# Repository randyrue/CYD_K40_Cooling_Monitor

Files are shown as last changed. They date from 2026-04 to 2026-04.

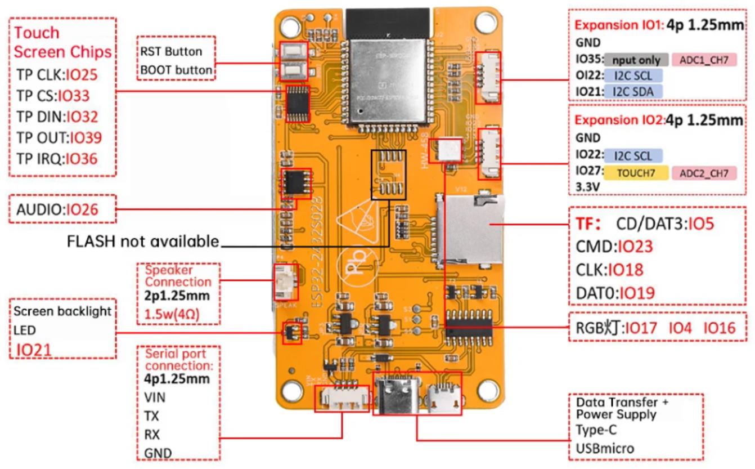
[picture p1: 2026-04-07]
pics/pinout.png

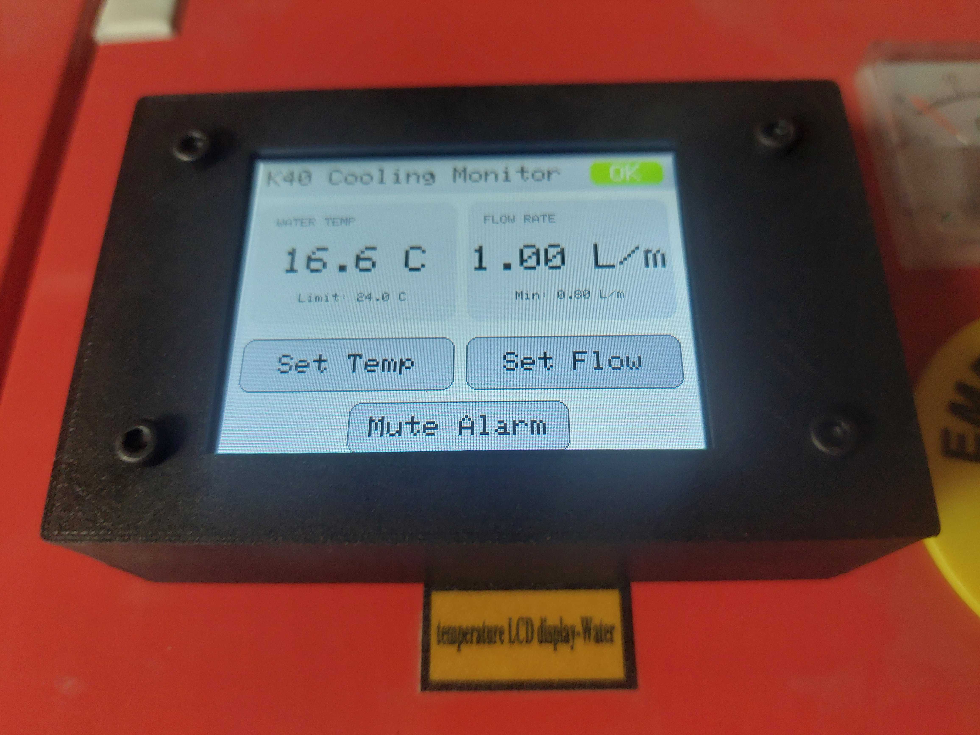
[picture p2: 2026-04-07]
pics/CYD_K40.jpg

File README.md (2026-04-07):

ESP32 Cheap Yellow Device K40 Laser Cooling Monitor

The CYD is about a perfect solution for upgrading the monitoring of cooling for a K40 CO2 laser cutter. Water flow and temperature are measured and if they go out of bounds (too warm or flow too low) the laser output is disabled.

My defaults are temp <= 24C and flow >= 0.8L/m. Change them in the code if your needs vary.

Minimal components are needed:

CYD
https://www.amazon.com/dp/B0CLR7MQ91
This is the one I used. There are many slight variations. You might need to fiddle with your User_Setup.h if yours is different. For example, I had to dink around for a while to get some colors to make sense.

DS18B20 temperature probe
https://www.amazon.com/dp/B012C597T0
Needs a 4K7 pull-up resistor between +V and the data line. Specs call for connecting the resistor to 3.3V, which you could get from the CN1 connector if needed, but mine works fine connected to 5V. For mine I added it in the middle of the cable to the temp sensor as long as I was splicing wires and wrapping the splices in heat shrink. This simplifies what would otherwise be your only needed wiring across the ports of the CYD.

GR-R401 fluid flow counter
https://www.amazon.com/dp/B07RF57QF8

Relay Module
https://www.amazon.com/dp/B00LW15A4W

Connectors for the onboard jacks: you'll need a few more than the one supplied with the CYD
https://www.amazon.com/dp/B0G146WVC1

Small Speaker

Case (STL file and SCAD are included here)
https://www.thingiverse.com/thing:7330724
Case design is a remix with no holes for connectors and extra space around the edges for JST headers. I drilled holes through the front for the CYD mounting holes, and a large hole through the back for wires to pass through. I should have also included one hole for the USB C jack in case I want to reflash the thing without needing to remove it. I've included the STL and also the hacked SCAD file, mod it to your preference.

A few other things make installation and maintenance easier, like:

Connector pigtails for the sensors - Tip - Reverse the M/F pigtail connectors for the temp and flow sensor connections to avoid confusion when climbing under your bench to connect them. That is, put the M on the controller side and the F on the sensor side for one, and the F on the controller side and the M on the sensor side for the other.
https://www.amazon.com/dp/B071H5XCN5

3-Conductor Wire - I added about four feet of three conductor wire between the sensors and the connector pigtails, with tidy splices and heat shrink tubing and for the temp sensor, its pullup resistor in one of the junctions (see Temperature Probe note above).
https://www.amazon.com/dp/B08JTZKN4M

Heat Shrink Tubing

Double Sided Tape

Hookup Wire

Connections to the K40: You essentially need to tap into +5VDC, ground, and wire the relay module's "NO" (normally open) side into the wire to the "P" connection on your high voltage power supply. Easy Peasy.

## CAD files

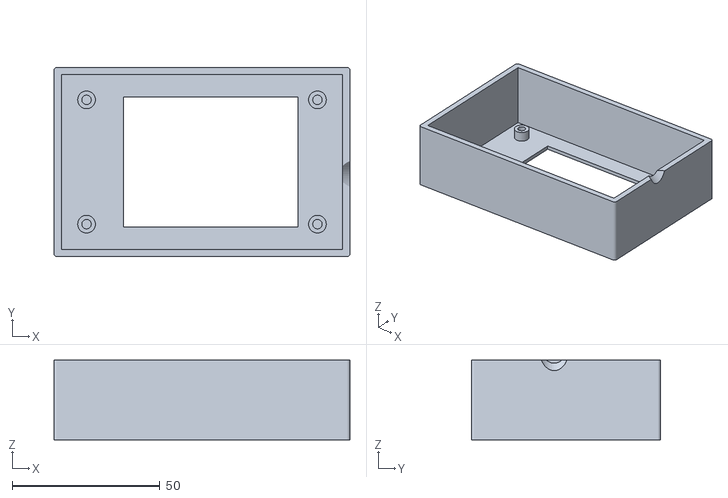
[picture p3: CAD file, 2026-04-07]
case/CYD_box.stl
100.0 x 64.0 x 27.0

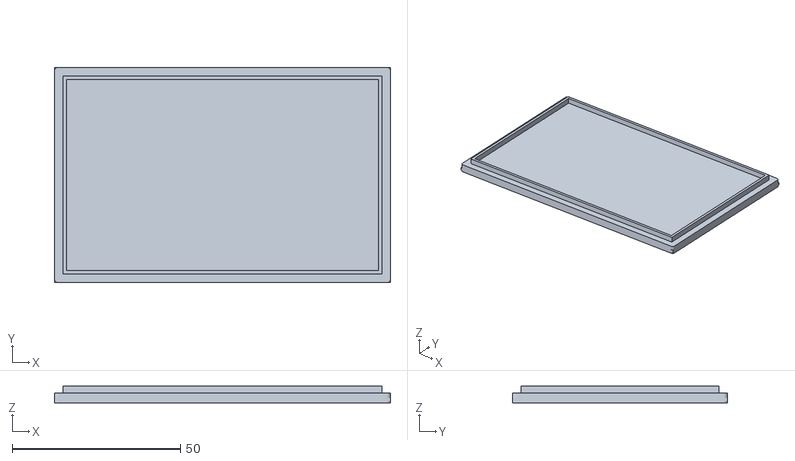
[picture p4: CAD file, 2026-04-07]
case/CYD_lid.stl
100.0 x 64.0 x 5.00

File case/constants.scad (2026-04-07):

// Constants
board_y_width = 51;
board_x_length = 87;
wall_thickness = 1.5;

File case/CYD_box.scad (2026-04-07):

// v4
$fn=40;


include <constants.scad>    // things shared with the lid
box_height = 26;
display_width = 44;
display_length = 59;
display_x_offset = 3;  // from the antenna end
display_y_offset = 4;
display_thickness = 3;  // from the main board
overlap = 0.01;
screw_mount_inset = 6;
screw_mount_height = 4;
screw_mount_radius = 3;
screw_hole_radius = 1.6;
board_thickness = 1.5;
usb_width = 12;
usb_y_offset = (screw_mount_height / 2) - 1.5;
opening_depth = 4;  // opening hole depth
board_top_z = screw_mount_height + board_thickness + wall_thickness; // opening hole z

include <roundedcube.scad>
//translate([-1,-1,0]) cube([100,64,10]);

difference() {
    minkowski() {
        cube([board_x_length+(wall_thickness*2+8), board_y_width+(wall_thickness*2+8), box_height]);
        cylinder(r=1,h=1);
        }
    
    // box main cavity
    translate([wall_thickness, wall_thickness, wall_thickness])
    cube([board_x_length+8, board_y_width+8, box_height]);
    
    // diplay opening
    translate([4+ (board_x_length / 2), 4+board_y_width / 2, -overlap])
    translate([wall_thickness+display_x_offset, wall_thickness, 0])
    cube([display_length, display_width, box_height], center=true);
    
    // USB-C port
    translate([-overlap, (board_y_width / 2) + wall_thickness, (box_height / 2) + usb_y_offset])
    roundedcube([10, usb_width, 6], radius = 2, center=true);
    
    // fingernail slot on end to help take off the lid
    finger_hole_radius=5;
    translate([board_x_length+finger_hole_radius+8, (board_y_width / 2) + wall_thickness, box_height+3.5])
    rotate([0,-45,0])
    cylinder(h=10, r=finger_hole_radius, center=true);

    // UART opening
    uart_width = 10;
    uart_height = 5;
    uart_start_x = 30.5 + wall_thickness;  // left edge
    //translate([uart_start_x, -overlap, board_top_z])
    //cube([uart_width, uart_height, opening_depth]);
    
    // SD Card opening
    sd_width = 16;
    sd_height = 2;
    sd_start_x = 43 + wall_thickness;
    //translate([sd_start_x, -overlap, board_top_z])
    //cube([sd_width, opening_depth, sd_height]);
    
    // SPI socket opening
    spi_width = 8;
    spi_height = 5;
    spi_start_x = 47.5 + wall_thickness;
    translate([spi_start_x, board_y_width + overlap, board_top_z])
    cube([spi_width, spi_height, opening_depth]);
    
    // IO35 socket opening
    io35_width = 8;
    io35_height = 5;
    io35_start_x = 64 + wall_thickness;
    translate([io35_start_x, board_y_width + overlap, board_top_z])
    cube([io35_width, io35_height, opening_depth]);
}

// screw mounts
corner_screws();

module corner_screws() {
    // right edge near USB socket
    translate([4+screw_mount_inset, 
        screw_mount_inset+4, 
        wall_thickness])
    screw_mount();
    
    // left edge near USB socket
    translate([4+screw_mount_inset, 
        board_y_width - screw_mount_inset + (wall_thickness*2)+4, 
        wall_thickness])
    screw_mount();
    
    // left far end from USB
    translate([4+board_x_length - screw_mount_inset + (wall_thickness*2), 
        board_y_width - screw_mount_inset + (wall_thickness*2)+4, 
        wall_thickness])
    screw_mount();
    
    // right far end from USB
    translate([4+board_x_length - screw_mount_inset + (wall_thickness*2), 
        screw_mount_inset+4, 
        wall_thickness])
    screw_mount();
}

module screw_mount() {
    //translate([6, 6, wall_thickness - overlap])
    difference() {
        cylinder(screw_mount_height, screw_mount_radius, screw_mount_radius); // h, r1, r2
        
        translate([0,0,wall_thickness])
        cylinder(screw_mount_height, screw_hole_radius, screw_hole_radius); // h, r1, r2
    }

}

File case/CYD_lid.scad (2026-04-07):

// Lid for the box
$fn=20;

include <constants.scad>
lid_layer_thickness = 2;
lid_inset = 0.2;

// top part full width
minkowski() {
    cube([8+board_x_length+(wall_thickness*2), 8+board_y_width+(wall_thickness*2), lid_layer_thickness], center = true);
    cylinder(r=1,h=1);
    }
translate([0, 0, lid_layer_thickness])
difference() {
// bit that fits into the hole in the box
    cube([8+board_x_length - lid_inset, 8+board_y_width - lid_inset, lid_layer_thickness+2], center = true);
    translate([0, 0, 0.1])
    cube([8+board_x_length - lid_inset - lid_layer_thickness, 8+board_y_width - lid_inset - lid_layer_thickness, lid_layer_thickness+2], center = true);

}

cube([100,64,1],center=true);

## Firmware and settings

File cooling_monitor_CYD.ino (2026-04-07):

// =============================================================================
//  K40 Laser Cooling Monitor — ESP32 Cheap Yellow Display (ESP32-2432S028)
// =============================================================================
//
//  Hardware connections:
//    DS18B20 data        -> GPIO 22  (P3 connector), 4.7kOhm pullup to 3.3V
//    DS18B20 VCC         -> 5V
//    DS18B20 GND         -> GND
//    Flow sensor signal  -> GPIO 35  (P3 connector)
//    Flow sensor VCC     -> 5V
//    Flow sensor GND     -> GND
//    Laser relay signal  -> GPIO 27  (CN1 connector)
//    Speaker (onboard)   -> GPIO 26  (SPEAK connector)
//    Power/GND           -> Serial port next to the USB C port (P1 connector)  
//
//  Relay wiring:
//    GPIO 27 is 3.3V logic. Use a relay module with 3.3V trigger, or drive
//    a 5V relay coil via a small NPN transistor (e.g. 2N2222). Relay output goes
//    connects between the existing connection to the "P" pin on the high voltage
//    power supply.
//
//  DS18B20 pullup:
//    4.7kOhm resistor between GPIO 22 and 5V. Note that specs call to connect it
//    to 3.3V but 5V seems to work and simplifies wiring.
//
//  Libraries required (Arduino Library Manager):
//    TFT_eSPI by Bodmer
//    XPT2046_Touchscreen by Paul Stoffregen
//    OneWire by Paul Stoffregen
//    DallasTemperature by Miles Burton
//
//  See User_Setup.h block at the bottom of this file. 
//
//  Boots in live mode. Hold the bottom button 3 seconds to toggle test mode.
//  Set minFlow to 0.00 L/m to disable flow fault checking entirely.
// =============================================================================

#include <TFT_eSPI.h>
#include <XPT2046_Touchscreen.h>
#include <OneWire.h>
#include <DallasTemperature.h>

// ---------------------------------------------------------------------------
//  Pin definitions
// ---------------------------------------------------------------------------
#define FLOW_SENSOR_PIN     35
#define DS18B20_PIN         22
#define RELAY_PIN           27
#define SPEAKER_PIN         26
#define TOUCH_CS            33
#define TOUCH_IRQ           36

// ---------------------------------------------------------------------------
//  DS18B20
// ---------------------------------------------------------------------------
OneWire oneWire(DS18B20_PIN);
DallasTemperature sensors(&oneWire);

// ---------------------------------------------------------------------------
//  Flow sensor
// ---------------------------------------------------------------------------
#define FLOW_CALIBRATION    98.0f      // pulses per litre/minute

// ---------------------------------------------------------------------------
//  Defaults
// ---------------------------------------------------------------------------
#define DEFAULT_MAX_TEMP    24.0f      // C   — above this triggers alarm
#define DEFAULT_MIN_FLOW     0.8f      // L/min — below this triggers alarm (0 = disabled)

// ---------------------------------------------------------------------------
//  Display / touch objects
// ---------------------------------------------------------------------------
TFT_eSPI tft = TFT_eSPI();
SPIClass touchSPI(VSPI);
XPT2046_Touchscreen touch(TOUCH_CS, TOUCH_IRQ);

// Touch calibration — confirmed from all four corner taps:
//   top-left:    raw( 467,  747)   top-right:    raw(3799,  677)
//   bottom-left: raw( 450, 3520)   bottom-right: raw(3769, 3670)
#define TS_MINX   450
#define TS_MAXX  3799
#define TS_MINY   677
#define TS_MAXY  3670

// ---------------------------------------------------------------------------
//  Globals
// ---------------------------------------------------------------------------
volatile uint32_t pulseCount = 0;
float flowRate  = 0.0f;
float waterTemp = 99.0f;   // safe default — triggers alarm until real reading

float maxTemp = DEFAULT_MAX_TEMP;
float minFlow = DEFAULT_MIN_FLOW;

bool alarmActive  = false;
bool alarmSilent  = false;
bool testMode     = false;   // boots in live mode; hold bottom button 3s to toggle

unsigned long lastFlowCalc   = 0;
unsigned long lastAlarmTone  = 0;
unsigned long muteHoldStart  = 0;
bool          muteHolding    = false;
uint8_t       muteReleaseCnt = 0;   // consecutive no-touch reads to confirm lift-off
#define RELEASE_NEEDED  6           // ~6 x 10ms = 60ms silence = genuine release

enum Screen { SCREEN_MAIN, SCREEN_SET_TEMP, SCREEN_SET_FLOW };
Screen currentScreen = SCREEN_MAIN;

// ---------------------------------------------------------------------------
//  ISR — counts flow sensor pulses
// ---------------------------------------------------------------------------
void IRAM_ATTR flowPulse() { pulseCount++; }

// ---------------------------------------------------------------------------
//  Read DS18B20 — returns 99.0 if disconnected so alarm fires safely
// ---------------------------------------------------------------------------
float readTemperature() {
  sensors.requestTemperatures();
  float t = sensors.getTempCByIndex(0);
  if (t == DEVICE_DISCONNECTED_C) return 99.0f;
  return t;
}

// ---------------------------------------------------------------------------
//  Flow rate — call every second, uses elapsed time for accuracy
// ---------------------------------------------------------------------------
void updateFlowRate() {
  unsigned long now     = millis();
  unsigned long elapsed = now - lastFlowCalc;
  if (elapsed < 1000) return;
  noInterrupts();
  uint32_t pulses = pulseCount;
  pulseCount = 0;
  interrupts();
  flowRate     = ((1000.0f / elapsed) * pulses) / FLOW_CALIBRATION;
  lastFlowCalc = now;
}

// ---------------------------------------------------------------------------
//  Relay / speaker
// ---------------------------------------------------------------------------
void setLaser(bool enable)  { digitalWrite(RELAY_PIN, enable ? HIGH : LOW); }
void soundAlarm()           { tone(SPEAKER_PIN, 3000, 120); }
void silenceAlarm()         { noTone(SPEAKER_PIN); }

// ---------------------------------------------------------------------------
//  Colours
//  0xE007 is byte-swapped green for this ST7789 board variant
// ---------------------------------------------------------------------------
#define COLOR_BG      TFT_BLACK
#define COLOR_HEADER  0x1082
#define COLOR_OK      0xE007
#define COLOR_WARN    TFT_RED
#define COLOR_ACCENT  0xFD20
#define COLOR_TEXT    TFT_WHITE
#define COLOR_SUBTEXT 0xAD75
#define COLOR_BTN     0x2945

// ---------------------------------------------------------------------------
//  Draw rounded button
// ---------------------------------------------------------------------------
void drawButton(int x, int y, int w, int h, const char* label,
                uint16_t bg = COLOR_BTN, uint16_t fg = COLOR_TEXT) {
  tft.fillRoundRect(x, y, w, h, 8, bg);
  tft.drawRoundRect(x, y, w, h, 8, COLOR_SUBTEXT);
  tft.setTextColor(fg, bg);
  tft.setTextDatum(MC_DATUM);
  tft.setTextSize(2);
  tft.drawString(label, x + w / 2, y + h / 2);
}

// ---------------------------------------------------------------------------
//  Update sensor value cards in place — no fillScreen, no flicker
//  Called every second when alarm state has not changed
// ---------------------------------------------------------------------------
void updateValues() {
  // Temp card — red tint if over limit
  uint16_t tCard = (waterTemp > maxTemp) ? 0x6000 : 0x0841;
  tft.fillRoundRect(8, 40, 148, 100, 10, tCard);
  tft.setTextColor(COLOR_SUBTEXT, tCard);
  tft.setTextDatum(ML_DATUM); tft.setTextSize(1);
  tft.drawString("WATER TEMP", 20, 56);
  char buf[16]; dtostrf(waterTemp, 4, 1, buf); strcat(buf, " C");
  tft.setTextColor(COLOR_TEXT, tCard);
  tft.setTextSize(3); tft.setTextDatum(MC_DATUM);
  tft.drawString(buf, 82, 90);
  tft.setTextSize(1); tft.setTextColor(COLOR_SUBTEXT, tCard);
  char limBuf[24]; snprintf(limBuf, sizeof(limBuf), "Limit: %.1f C", maxTemp);
  tft.drawString(limBuf, 82, 120);

  // Flow card — red tint only if minFlow > 0 and flow is below limit.
  // When minFlow == 0 flow checking is disabled so card stays neutral always.
  uint16_t fCard = (minFlow > 0.0f && flowRate < minFlow) ? 0x6000 : 0x0841;
  tft.fillRoundRect(164, 40, 148, 100, 10, fCard);
  tft.setTextColor(COLOR_SUBTEXT, fCard);
  tft.setTextDatum(ML_DATUM); tft.setTextSize(1);
  tft.drawString("FLOW RATE", 176, 56);
  char fBuf[16]; dtostrf(flowRate, 4, 2, fBuf); strcat(fBuf, " L/m");
  tft.setTextColor(COLOR_TEXT, fCard);
  tft.setTextSize(3); tft.setTextDatum(MC_DATUM);
  tft.drawString(fBuf, 238, 90);
  tft.setTextSize(1); tft.setTextColor(COLOR_SUBTEXT, fCard);
  snprintf(limBuf, sizeof(limBuf), "Min: %.2f L/m", minFlow);
  tft.drawString(limBuf, 238, 120);
}

// ---------------------------------------------------------------------------
//  Full screen redraw — called on alarm state change, screen switch, or boot
// ---------------------------------------------------------------------------
void drawMainScreen(bool redBackground) {
  tft.fillScreen(redBackground ? COLOR_WARN : COLOR_BG);
  tft.fillRect(0, 0, 320, 32, redBackground ? 0x8000 : COLOR_HEADER);
  tft.setTextColor(COLOR_TEXT, redBackground ? 0x8000 : COLOR_HEADER);
  tft.setTextDatum(ML_DATUM); tft.setTextSize(2);
  tft.drawString("K40 Cooling Monitor", 8, 16);

  // Badge always reflects actual alarm state, not background colour
  if (alarmActive) {
    tft.fillRoundRect(240, 6, 72, 22, 6, TFT_YELLOW);
    tft.setTextColor(TFT_RED, TFT_YELLOW);
    tft.setTextDatum(MC_DATUM); tft.setTextSize(2);
    tft.drawString("FAULT", 276, 17);
  } else {
    tft.fillRoundRect(256, 6, 56, 22, 6, COLOR_OK);
    tft.setTextColor(TFT_BLACK, COLOR_OK);
    tft.setTextDatum(MC_DATUM); tft.setTextSize(2);
    tft.drawString("OK", 284, 17);
  }

  // Temp card — red-tinted if over limit
  uint16_t tCard = (waterTemp > maxTemp) ? 0x6000 : 0x0841;
  tft.fillRoundRect(8, 40, 148, 100, 10, tCard);
  tft.setTextColor(COLOR_SUBTEXT, tCard);
  tft.setTextDatum(ML_DATUM); tft.setTextSize(1);
  tft.drawString("WATER TEMP", 20, 56);
  char buf[16]; dtostrf(waterTemp, 4, 1, buf); strcat(buf, " C");
  tft.setTextColor(COLOR_TEXT, tCard);
  tft.setTextSize(3); tft.setTextDatum(MC_DATUM);
  tft.drawString(buf, 82, 90);
  tft.setTextSize(1); tft.setTextColor(COLOR_SUBTEXT, tCard);
  char limBuf[24]; snprintf(limBuf, sizeof(limBuf), "Limit: %.1f C", maxTemp);
  tft.drawString(limBuf, 82, 120);

  // Flow card — red tint only if minFlow > 0 and flow is below limit
  uint16_t fCard = (minFlow > 0.0f && flowRate < minFlow) ? 0x6000 : 0x0841;
  tft.fillRoundRect(164, 40, 148, 100, 10, fCard);
  tft.setTextColor(COLOR_SUBTEXT, fCard);
  tft.setTextDatum(ML_DATUM); tft.setTextSize(1);
  tft.drawString("FLOW RATE", 176, 56);
  char fBuf[16]; dtostrf(flowRate, 4, 2, fBuf); strcat(fBuf, " L/m");
  tft.setTextColor(COLOR_TEXT, fCard);
  tft.setTextSize(3); tft.setTextDatum(MC_DATUM);
  tft.drawString(fBuf, 238, 90);
  tft.setTextSize(1); tft.setTextColor(COLOR_SUBTEXT, fCard);
  snprintf(limBuf, sizeof(limBuf), "Min: %.2f L/m", minFlow);
  tft.drawString(limBuf, 238, 120);

  drawButton(8,   152, 148, 40, "Set Temp");
  drawButton(164, 152, 148, 40, "Set Flow");

  if (testMode)
    drawButton(60, 200, 200, 36, "TEST MODE (hold 3s)", 0x8400);
  else if (alarmSilent)
    drawButton(86, 200, 148, 36, "Unmute Alarm", COLOR_ACCENT);
  else
    drawButton(86, 200, 148, 36, "Mute Alarm", COLOR_BTN);
}

// ---------------------------------------------------------------------------
//  Settings screen
// ---------------------------------------------------------------------------
void drawSettingsScreen(bool isTemp) {
  tft.fillScreen(COLOR_BG);
  tft.fillRect(0, 0, 320, 32, COLOR_HEADER);
  tft.setTextColor(COLOR_TEXT, COLOR_HEADER);
  tft.setTextDatum(ML_DATUM); tft.setTextSize(2);
  tft.drawString(isTemp ? "Set Max Temperature" : "Set Min Flow Rate", 8, 16);

  tft.fillRoundRect(60, 50, 200, 70, 12, COLOR_BTN);
  tft.setTextDatum(MC_DATUM);
  tft.setTextColor(COLOR_TEXT, COLOR_BTN); tft.setTextSize(3);
  char valBuf[16];
  if (isTemp) { dtostrf(maxTemp, 4, 1, valBuf); strcat(valBuf, " C"); }
  else        { dtostrf(minFlow, 4, 2, valBuf); strcat(valBuf, " L/m"); }
  tft.drawString(valBuf, 160, 85);
  tft.setTextSize(1); tft.setTextColor(COLOR_SUBTEXT, COLOR_BTN);
  // Hint changes when flow check is disabled to make 0 = off obvious
  if (isTemp)
    tft.drawString("Max allowed temp", 160, 108);
  else
    tft.drawString(minFlow == 0.0f ? "Flow check DISABLED" : "Min required flow (0=off)", 160, 108);

  drawButton(10,  140, 110, 56, "-0.1", 0x2104);
  drawButton(130, 140,  60, 56, "-1",   0x2104);
  drawButton(200, 140,  60, 56, "+1",   0x03E0);
  drawButton(270, 140,  40, 56, "+0.1", 0x03E0);
  drawButton(60,  204, 200, 36, "Done", COLOR_ACCENT);
}

// ---------------------------------------------------------------------------
//  Touch handler — main screen
// ---------------------------------------------------------------------------
void handleTouchMain(int tx, int ty) {
  if (tx >= 8 && tx <= 156 && ty >= 152 && ty <= 192) {
    currentScreen = SCREEN_SET_TEMP;
    drawSettingsScreen(true);
  } else if (tx >= 164 && tx <= 312 && ty >= 152 && ty <= 192) {
    currentScreen = SCREEN_SET_FLOW;
    drawSettingsScreen(false);
  } else if (tx >= 60 && tx <= 260 && ty >= 200 && ty <= 236) {
    muteHolding    = true;
    muteHoldStart  = millis();
    muteReleaseCnt = 0;
  }
}

// ---------------------------------------------------------------------------
//  Hold detection — polled every 10ms
//  Short tap: mute/unmute in live mode
//  Hold 3s:   toggle test/live mode
// ---------------------------------------------------------------------------
void checkMuteHold() {
  if (!muteHolding) return;

  // 3 seconds elapsed — toggle mode, don't wait for lift-off
  if (millis() - muteHoldStart >= 3000) {
    testMode       = !testMode;
    muteHolding    = false;
    muteReleaseCnt = 0;
    if (testMode) {
      setLaser(false);
      silenceAlarm();
      alarmActive = false;
      alarmSilent = false;
    }
    tft.fillScreen(testMode ? 0x8400 : COLOR_OK);
    tft.setTextDatum(MC_DATUM);
    tft.setTextColor(TFT_WHITE, testMode ? 0x8400 : COLOR_OK);
    tft.setTextSize(3);
    tft.drawString(testMode ? "TEST MODE ON" : "LIVE MODE ON", 160, 120);
    delay(1000);
    drawMainScreen(false);
    return;
  }

  // Not yet 3s — require RELEASE_NEEDED consecutive no-touch reads before
  // treating as genuine lift-off (suppresses XPT2046 dropout noise mid-hold)
  if (touch.touched()) {
    muteReleaseCnt = 0;
  } else {
    muteReleaseCnt++;
    if (muteReleaseCnt >= RELEASE_NEEDED) {
      muteReleaseCnt = 0;
      muteHolding    = false;
      if (!testMode) {
        alarmSilent = !alarmSilent;
        if (alarmSilent) silenceAlarm();
        drawMainScreen(false);
      }
    }
  }
}

// ---------------------------------------------------------------------------
//  Touch handler — settings screens
// ---------------------------------------------------------------------------
void handleTouchSettings(int tx, int ty, bool isTemp) {
  float step = 0.0f;
  if (ty >= 140 && ty <= 196) {
    if      (tx >=  10 && tx <= 120) step = -0.1f;
    else if (tx >= 130 && tx <= 190) step = -1.0f;
    else if (tx >= 200 && tx <= 260) step =  1.0f;
    else if (tx >= 270 && tx <= 310) step =  0.1f;
  }
  if (step != 0.0f) {
    if (isTemp) maxTemp = constrain(maxTemp + step, 10.0f, 40.0f);
    else        minFlow = constrain(minFlow + step, 0.0f,  5.0f);  // 0 = flow check disabled
    drawSettingsScreen(isTemp);
    return;
  }
  if (tx >= 60 && tx <= 260 && ty >= 204 && ty <= 240) {
    currentScreen = SCREEN_MAIN;
    drawMainScreen(false);
  }
}

// ---------------------------------------------------------------------------
//  Touch coordinate mapping
//  raw X (450..3799) -> screen X (0..319)
//  raw Y (677..3670) -> screen Y (0..239)
// ---------------------------------------------------------------------------
void mapTouch(TS_Point p, int &sx, int &sy) {
  sx = map(p.x, TS_MINX, TS_MAXX, 0, 320);
  sy = map(p.y, TS_MINY, TS_MAXY, 0, 240);
  sx = constrain(sx, 0, 319);
  sy = constrain(sy, 0, 239);
}

// ---------------------------------------------------------------------------
//  setup()
// ---------------------------------------------------------------------------
void setup() {
  Serial.begin(115200);
  delay(1000);

  pinMode(RELAY_PIN,       OUTPUT);
  pinMode(SPEAKER_PIN,     OUTPUT);
  setLaser(false);

  pinMode(FLOW_SENSOR_PIN, INPUT_PULLUP);
  attachInterrupt(digitalPinToInterrupt(FLOW_SENSOR_PIN), flowPulse, FALLING);
  lastFlowCalc = millis();

  sensors.begin();

  tft.init();
  tft.setRotation(1);
  tft.fillScreen(TFT_BLACK);

  touchSPI.begin(25, 39, 32, TOUCH_CS);
  touch.begin(touchSPI);

  tft.setTextColor(TFT_WHITE, TFT_BLACK);
  tft.setTextDatum(MC_DATUM); tft.setTextSize(2);
  tft.drawString("K40 Cooling Monitor", 160, 100);
  tft.setTextSize(1); tft.setTextColor(COLOR_SUBTEXT, TFT_BLACK);
  tft.drawString(testMode ? "TEST MODE  hold bottom 3s to go live"
                          : "Starting in live mode...", 160, 130);
  delay(1500);
  drawMainScreen(false);
}

// ---------------------------------------------------------------------------
//  loop()
// ---------------------------------------------------------------------------
void loop() {
  unsigned long now = millis();

  // Hold detection polled every 10ms
  static unsigned long lastHoldCheck = 0;
  if (currentScreen == SCREEN_MAIN && now - lastHoldCheck >= 10) {
    lastHoldCheck = now;
    checkMuteHold();
  }

  // Update sensors and redraw once per second
  static unsigned long lastSensorUpdate = 0;
  if (now - lastSensorUpdate >= 1000) {
    lastSensorUpdate = now;

    if (testMode) {
      waterTemp = 20.0f;
      flowRate  = 1.5f;
      noInterrupts(); pulseCount = 0; interrupts();
      lastFlowCalc = now;
    } else {
      updateFlowRate();
      waterTemp = readTemperature();
    }

    // Alarm logic with hysteresis — triggers at limit, clears only past deadband:
    //   temp:  triggers above maxTemp,    clears below (maxTemp - 0.5C)
    //   flow:  triggers below minFlow,    clears above (minFlow x 1.1)
    //   flow fault skipped entirely when minFlow == 0
    if (!testMode) {
      bool tempFault = waterTemp > maxTemp;
      bool flowFault = (minFlow > 0.0f) && (flowRate < minFlow);
      if (tempFault || flowFault) {
        alarmActive = true;
      } else if (alarmActive) {
        bool tempOK = waterTemp < (maxTemp - 0.5f);
        bool flowOK = (minFlow == 0.0f) || (flowRate > (minFlow * 1.1f));
        if (tempOK && flowOK) alarmActive = false;
      }
    } else {
      alarmActive = false;
    }

    if (!testMode) {
      if (alarmActive) { setLaser(false); }
      else { setLaser(true); silenceAlarm(); alarmSilent = false; }
    }

    // Full redraw only when alarm state changes; otherwise just repaint cards
    static bool lastAlarmState = false;
    if (currentScreen == SCREEN_MAIN) {
      if (alarmActive != lastAlarmState) {
        lastAlarmState = alarmActive;
        drawMainScreen(alarmActive);
      } else {
        updateValues();
      }
    }
  }

  // Alarm tone every 600ms
  if (alarmActive && !alarmSilent && now - lastAlarmTone >= 600) {
    soundAlarm(); lastAlarmTone = now;
  }

  // Touch handling — fires once per press, not continuously while held
  static bool wasHeld = false;
  bool isTouched = touch.tirqTouched() && touch.touched();
  if (isTouched && !wasHeld) {
    TS_Point raw = touch.getPoint();
    int sx, sy;
    mapTouch(raw, sx, sy);
    Serial.printf("Touch: raw(%d,%d) -> screen(%d,%d)\n", raw.x, raw.y, sx, sy);
    if (!muteHolding) delay(80);
    switch (currentScreen) {
      case SCREEN_MAIN:     handleTouchMain(sx, sy);           break;
      case SCREEN_SET_TEMP: handleTouchSettings(sx, sy, true); break;
      case SCREEN_SET_FLOW: handleTouchSettings(sx, sy, false);break;
    }
  }
  wasHeld = isTouched;
}

// =============================================================================
//  User_Setup.h — DELETE everything in that file and replace with this:
// =============================================================================
//
//  #define ST7789_DRIVER
//  #define TFT_WIDTH  240
//  #define TFT_HEIGHT 320
//
//  // Do NOT define TFT_RGB_ORDER — ST7789 on this board wants plain RGB
//
//  #define TFT_MOSI  13
//  #define TFT_MISO  12
//  #define TFT_SCLK  14
//  #define TFT_CS    15
//  #define TFT_DC     2
//  #define TFT_RST   -1
//  #define TFT_BL    21
//  #define TFT_BACKLIGHT_ON HIGH
//
//  #define USE_HSPI_PORT
//
//  // TOUCH_CS intentionally not defined here — XPT2046 is driven on its own
//  // VSPI bus by the XPT2046_Touchscreen library directly in the sketch.
//
//  #define SPI_FREQUENCY        40000000
//  #define SPI_READ_FREQUENCY    6000000
//  #define SPI_TOUCH_FREQUENCY    800000
//
//  #define LOAD_GLCD
//  #define LOAD_FONT2
//  #define LOAD_FONT4
//  #define LOAD_FONT6
//  #define LOAD_FONT7
//  #define LOAD_FONT8
//  #define LOAD_GFXFF
//  #define SMOOTH_FONT
// =============================================================================
